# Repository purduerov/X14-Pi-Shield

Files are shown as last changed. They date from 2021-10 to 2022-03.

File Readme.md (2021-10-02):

# Readme for X14-Pi-Shield

Whenever you make a new part, download the datasheet and save it here _**and**_ with the part in the parts library

Always pull other people's changes before beginning to work
`git pull`

Be sure to push your changes after  working on them. Run:
1. `git add .` to add any files in this directory or a subdirectory
or `git add -u` to add any modified files
2. (Optional) `git clean -nX` to see what ignored files can be removed
	`git clean -fX` removes ignored files (Eagle backups)
3. `git commit -m "helpful commit message"` with a description of the work that you did
4. `git push` to push your work to github

Other helpful commands
* `git status` says information about modified and staged files
* `git log` shows the recent commits of the repository
* `git log filename.extension` show the recent commits for just that file
* `git checkout first-couple-letter-of-commit-id` lets you go back to a previous version
* `git checkout master` brings you back to the latest commit
* `git tag` lists the tags
* `git tag -a orderX -m "the version of the board placed for the X'th order"` tag a specific commit
* `git push --tags` needed to push tags to remote
* `git show orderX` show the commit log for the given tag
* `git checkout orderX` go back and interact with the files at the tagged commit

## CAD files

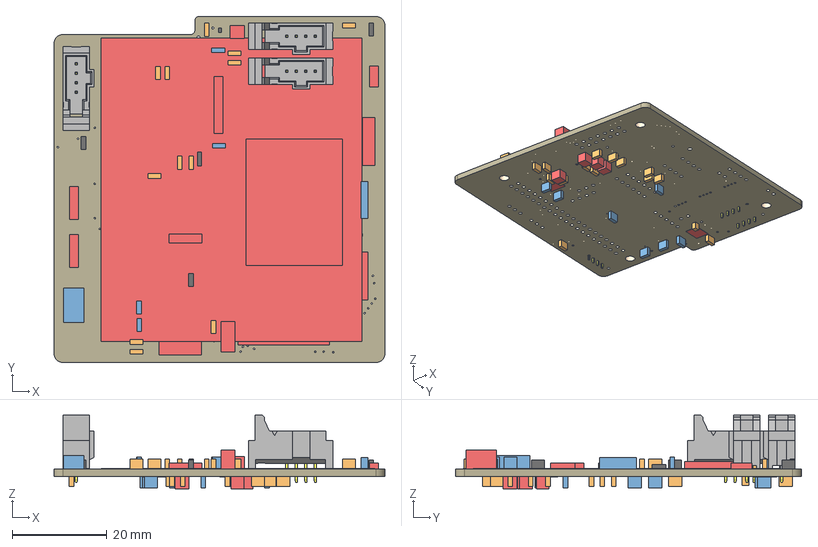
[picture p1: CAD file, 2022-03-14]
PI-Shield.step
69.8 x 73.0 x 15.5 mm
Board
0.1uF x 11
47uF
150uF
250mA/100V
COLOR
LED-0603 x 3
1X04 x 2
_T2I-04-VT-T-S-TH_terminal x 3
_T2I-04-VT-T-S-TH_pins x 3
DF13-4P-1.25DSA x 3
1X03 x 3
1X05
1X02
1X02 (1) x 2
2.5A/30V/105mΩ x 5
JUMPER-SMT_2_NO_SILK
MCP2515
TCAN337D
ADAFRUIT-FXOS8700-FXAS21002
ADAFRUIT-BNO055
DISCRETECOMPONENTS_SW_2512
MCR1101
RPI4
MAX1136EUA-T
ULN2003V12
ECS-80-S-4X
7X_CONN

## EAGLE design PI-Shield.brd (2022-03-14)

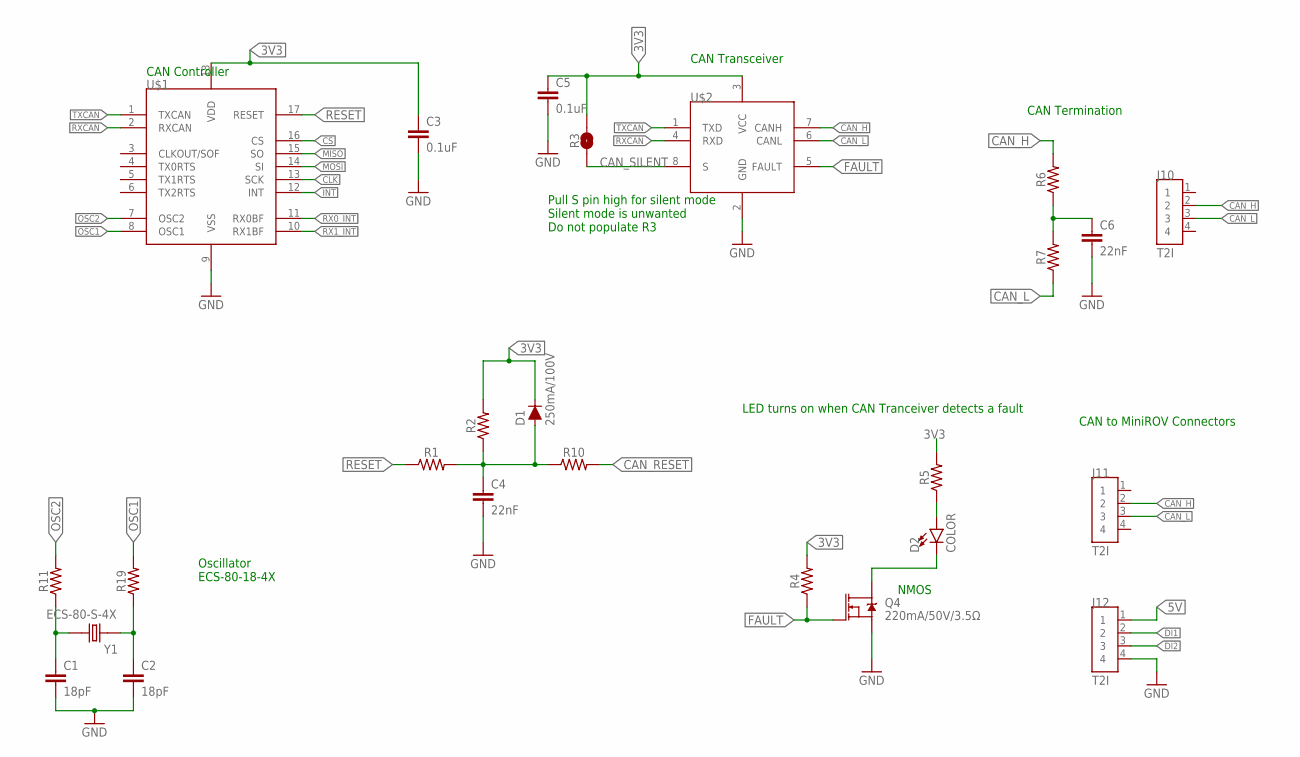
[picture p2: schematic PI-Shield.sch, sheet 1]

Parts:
C1, C2: 18pF; 0603
C3, C5: 0.1uF; 0603
C4, C6: 22nF; 0603
D1: 250mA/100V; SOD-323
D2: COLOR; 0805
J10, J11, J12: T2I
Q4: 220mA/50V/3.5Ω; SOT23-3
R1, R2, R4, R5, R6, R7, R10, R11, R19: 0603
R3: JUMPER-SMT_2_NO_SILK; SMT-JUMPER_2_NO_SILK
U$1: MCP2515; SOIC-18
U$2: TCAN337D; SOIC-8
Y1: ECS-80-S-4X; XTAL_ECS-80-S-4X

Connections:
3V3: C3.1, C5.1, D1.C, R2.2, R3.2, R4.2, R5.2, U$1.18 (VDD), U$2.3 (VCC); also elsewhere on the board
5V: J12.1; also elsewhere on the board
CAN_H: J10.2, J11.2, R6.2, U$2.7 (CANH); also elsewhere on the board
CAN_L: J10.3, J11.3, R7.1, U$2.6 (CANL); also elsewhere on the board
CAN_RESET: R10.2; also elsewhere on the board
CAN_SILENT: R3.1, U$2.8 (S)
CAN_TERM_COM: C6.1, R6.1, R7.2
CLK: U$1.13 (SCK); also elsewhere on the board
CS: U$1.16 (CS); also elsewhere on the board
DI1: J12.2; also elsewhere on the board
DI2: J12.3; also elsewhere on the board
FAULT: Q4.1 (G), R4.1, U$2.5 (FAULT)
GND: C1.2, C2.2, C3.2, C4.2, C5.2, C6.2, J12.4, Q4.2 (S), U$1.9 (VSS), U$2.2 (GND); also elsewhere on the board
INT: U$1.12 (INT); also elsewhere on the board
MISO: U$1.15 (SO); also elsewhere on the board
MOSI: U$1.14 (SI); also elsewhere on the board
unnamed: C1.1, R11.1, Y1.2
unnamed: C2.1, R19.1, Y1.1
unnamed: D2.C, Q4.3 (D)
unnamed: D2.A, R5.1
OSC1: R19.2, U$1.8 (OSC1)
OSC2: R11.2, U$1.7 (OSC2)
RESET: R1.1, U$1.17 (RESET)
RESET_MID: C4.1, D1.A, R1.2, R2.1, R10.1
RX0_INT: U$1.11 (RX0BF); also elsewhere on the board
RX1_INT: U$1.10 (RX1BF); also elsewhere on the board
RXCAN: U$1.2 (RXCAN), U$2.4 (RXD)
TXCAN: U$1.1 (TXCAN), U$2.1 (TXD)

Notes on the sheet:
Oscillator ECS-80-18-4X
CAN Termination
CAN to MiniROV Connectors
NMOS
CAN Controller
CAN Transceiver
Pull S pin high for silent mode Silent mode is unwanted Do not populate R3
LED turns on when CAN Tranceiver detects a fault

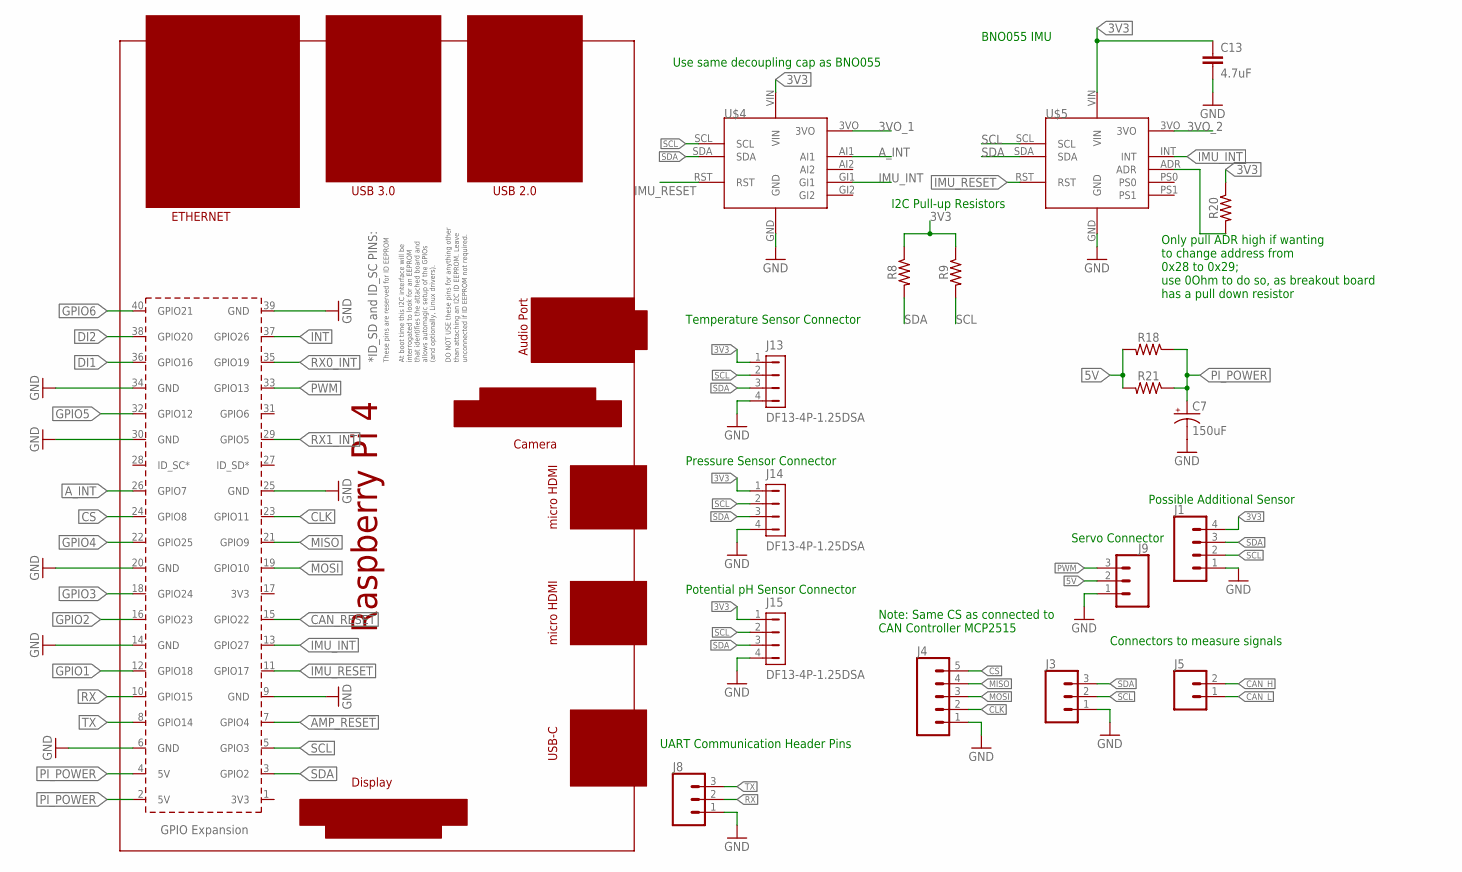
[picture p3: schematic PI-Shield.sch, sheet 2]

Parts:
C7: 150uF; 2917(7343-31-METRIC)
C13: 4.7uF; 0603
J1: CONN_04; 1X04
J3, J8, J9: CONN_03; 1X03
J4: CONN_05; 1X05
J5: CONN_02; 1X02
J13, J14, J15: DF13-4P-1.25DSA
R8, R9, R18, R20, R21: 0603
U$4: ADAFRUIT-FXOS8700-FXAS21002
U$5: ADAFRUIT-BNO055
U$8: RPI4

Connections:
3V3: C13.1, J1.4, J13.1, J14.1, J15.1, R8.1, R9.1, R20.1, U$4.VIN, U$5.VIN; also elsewhere on the board
3VO_1: U$4.3VO
3VO_2: U$5.3VO
5V: J9.2, R18.2, R21.2; also elsewhere on the board
!AMP_RESET: U$8.7 (GPIO4); also elsewhere on the board
A_INT: U$4.AI1, U$8.26 (GPIO7)
CAN_H: J5.2; also elsewhere on the board
CAN_L: J5.1; also elsewhere on the board
CAN_RESET: U$8.15 (GPIO22); also elsewhere on the board
CLK: J4.2, U$8.23 (GPIO11); also elsewhere on the board
CS: J4.5, U$8.24 (GPIO8); also elsewhere on the board
DI1: U$8.36 (GPIO16); also elsewhere on the board
DI2: U$8.38 (GPIO20); also elsewhere on the board
GND: C7.-, C13.2, J1.1, J3.1, J4.1, J8.1, J9.1, J13.4, J14.4, J15.4, U$4.GND, U$5.GND, U$8.6 (GND), U$8.9 (GND), U$8.14 (GND), U$8.20 (GND), U$8.25 (GND), U$8.30 (GND), U$8.34 (GND), U$8.39 (GND); also elsewhere on the board
GPIO1: U$8.12 (GPIO18); also elsewhere on the board
GPIO2: U$8.16 (GPIO23); also elsewhere on the board
GPIO3: U$8.18 (GPIO24); also elsewhere on the board
GPIO4: U$8.22 (GPIO25); also elsewhere on the board
GPIO5: U$8.32 (GPIO12); also elsewhere on the board
GPIO6: U$8.40 (GPIO21); also elsewhere on the board
IMU_INT: U$4.GI1, U$5.INT, U$8.13 (GPIO27)
IMU_RESET: U$4.RST, U$5.RST, U$8.11 (GPIO17)
INT: U$8.37 (GPIO26); also elsewhere on the board
MISO: J4.4, U$8.21 (GPIO9); also elsewhere on the board
MOSI: J4.3, U$8.19 (GPIO10); also elsewhere on the board
unnamed: R20.2, U$5.ADR
PI_POWER: C7.+, R18.1, R21.1, U$8.2 (5V), U$8.4 (5V)
PWM: J9.3, U$8.33 (GPIO13)
RX: J8.2, U$8.10 (GPIO15)
RX0_INT: U$8.35 (GPIO19); also elsewhere on the board
RX1_INT: U$8.29 (GPIO5); also elsewhere on the board
SCL: J1.2, J3.2, J13.2, J14.2, J15.2, R9.2, U$4.SCL, U$5.SCL, U$8.5 (GPIO3); also elsewhere on the board
SDA: J1.3, J3.3, J13.3, J14.3, J15.3, R8.2, U$4.SDA, U$5.SDA, U$8.3 (GPIO2); also elsewhere on the board
TX: J8.3, U$8.8 (GPIO14)

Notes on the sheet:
Connectors to measure signals
Temperature Sensor Connector
Pressure Sensor Connector
Potential pH Sensor Connector
BNO055 IMU
Possible Additional Sensor
UART Communication Header Pins
Servo Connector
Only pull ADR high if wanting to change address from 0x28 to 0x29; use 0Ohm to do so, as breakout board has a pull down resistor
Use same decoupling cap as BNO055
I2C Pull-up Resistors
Note: Same CS as connected to CAN Controller MCP2515

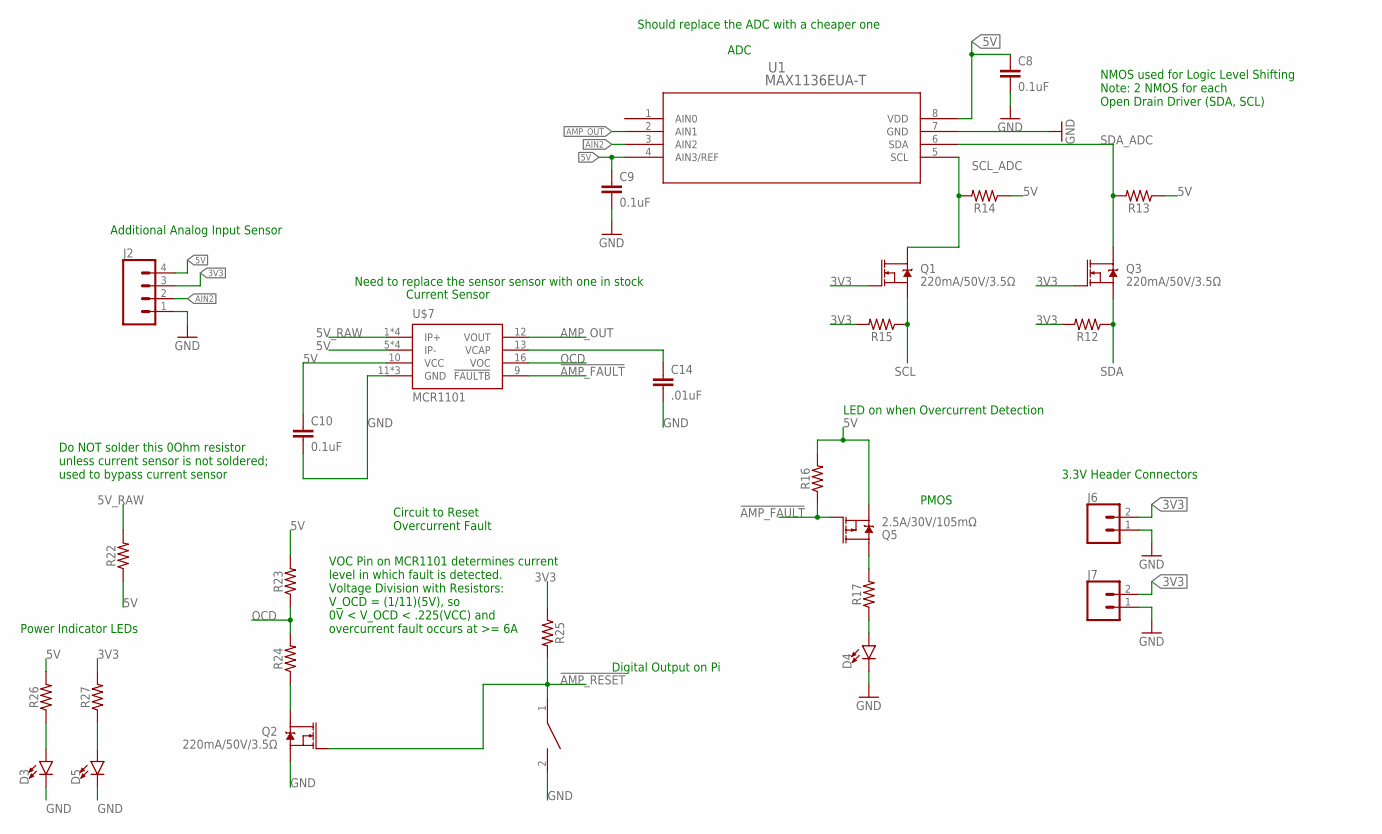
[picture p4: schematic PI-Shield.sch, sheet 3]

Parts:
C8, C9, C10: 0.1uF; 0603
C14: .01uF; 0603
D3, D4, D5: LED0603; LED-0603
J2: CONN_04; 1X04
J6, J7: CONN_02; 1X02
Q1, Q2, Q3: 220mA/50V/3.5Ω; SOT23-3
Q5: 2.5A/30V/105mΩ; SOT23-3
R12, R13, R14, R15, R16, R17, R22, R23, R24, R25, R26, R27: 0603
U1: MAX1136EUA-T; 21-0036K
U$6: DISCRETECOMPONENTS_SWITCH; DISCRETECOMPONENTS_SW_2512
U$7: MCR1101; SOIC-16

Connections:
3V3: J2.3, J6.2, J7.2, Q1.1 (G), Q3.1 (G), R12.2, R15.2, R25.1, R27.2; also elsewhere on the board
5V: C8.1, C9.1, C10.1, J2.4, Q5.2 (S), R13.1, R14.1, R16.2, R22.1, R23.2, R26.2, U1.4 (AIN3/REF), U1.8 (VDD), U$7.5 (IP-), U$7.6 (IP-), U$7.7 (IP-), U$7.8 (IP-), U$7.10 (VCC); also elsewhere on the board
5V_RAW: R22.2, U$7.1 (IP+), U$7.2 (IP+), U$7.3 (IP+), U$7.4 (IP+)
!AMP_FAULT: Q5.1 (G), R16.1, U$7.9 (!FAULTB)
!AMP_RESET: Q2.1 (G), R25.2, U$6.1; also elsewhere on the board
AIN2: J2.2, U1.3 (AIN2)
AMP_OUT: U1.2 (AIN1), U$7.12 (VOUT)
GND: C8.2, C9.2, C10.2, C14.2, D3.C, D4.C, D5.C, J2.1, J6.1, J7.1, Q2.2 (S), U1.7 (GND), U$6.2, U$7.11 (GND), U$7.14 (GND), U$7.15 (GND); also elsewhere on the board
unnamed: C14.1, U$7.13 (VCAP)
unnamed: D3.A, R26.1
unnamed: Q5.3 (D), R17.2
unnamed: D4.A, R17.1
unnamed: D5.A, R27.1
unnamed: Q2.3 (D), R24.1
OCD: R23.1, R24.2, U$7.16 (VOC)
SCL: Q1.2 (S), R15.1; also elsewhere on the board
SCL_ADC: Q1.3 (D), R14.2, U1.5 (SCL)
SDA: Q3.2 (S), R12.1; also elsewhere on the board
SDA_ADC: Q3.3 (D), R13.2, U1.6 (SDA)

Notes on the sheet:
ADC
Additional Analog Input Sensor
3.3V Header Connectors
PMOS
LED on when Overcurrent Detection
NMOS used for Logic Level Shifting Note: 2 NMOS for each Open Drain Driver (SDA, SCL)
Do NOT solder this 0Ohm resistor unless current sensor is not soldered; used to bypass current sensor
Current Sensor
Circuit to Reset Overcurrent Fault
Need to replace the sensor sensor with one in stock
Should replace the ADC with a cheaper one
Power Indicator LEDs
VOC Pin on MCR1101 determines current level in which fault is detected. Voltage Division with Resistors: V_OCD = (1/11)(5V), so 0V < V_OCD < .225(VCC) and overcurrent fault occurs at >= 6A
Digital Output on Pi

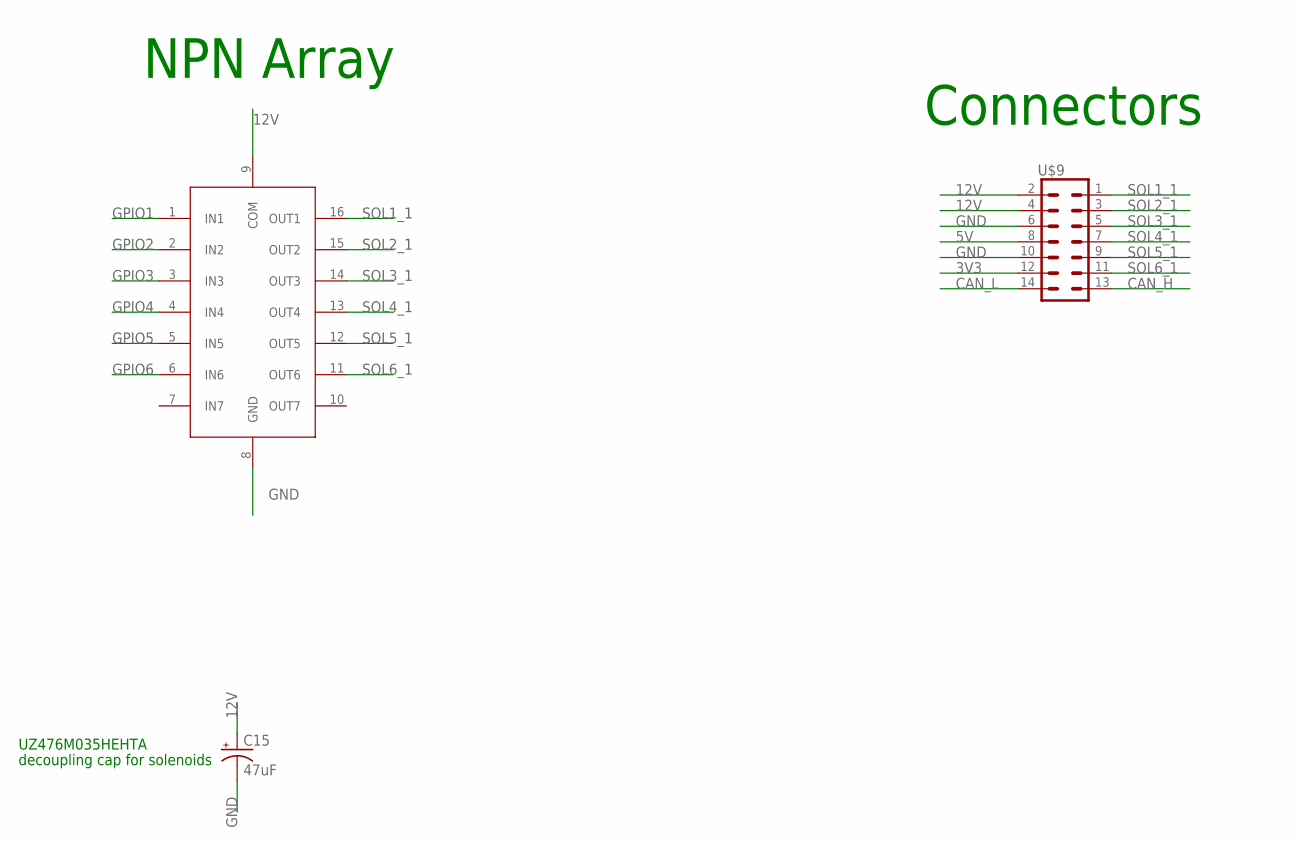
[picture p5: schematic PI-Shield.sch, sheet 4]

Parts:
C15: 47uF; PANASONIC_D
U3: ULN2003V12
U$9: 7X_CONN; IPL7X2

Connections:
3V3: U$9.12 (23); also elsewhere on the board
5V: U$9.8 (19); also elsewhere on the board
12V: C15.+, U3.9 (COM), U$9.2 (13), U$9.4 (15)
CAN_H: U$9.13 (1); also elsewhere on the board
CAN_L: U$9.14 (2); also elsewhere on the board
GND: C15.-, U3.8 (GND), U$9.6 (17), U$9.10 (21); also elsewhere on the board
GPIO1: U3.1 (IN1); also elsewhere on the board
GPIO2: U3.2 (IN2); also elsewhere on the board
GPIO3: U3.3 (IN3); also elsewhere on the board
GPIO4: U3.4 (IN4); also elsewhere on the board
GPIO5: U3.5 (IN5); also elsewhere on the board
GPIO6: U3.6 (IN6); also elsewhere on the board
SOL1_1: U3.16 (OUT1), U$9.1 (14)
SOL2_1: U3.15 (OUT2), U$9.3 (16)
SOL3_1: U3.14 (OUT3), U$9.5 (18)
SOL4_1: U3.13 (OUT4), U$9.7 (20)
SOL5_1: U3.12 (OUT5), U$9.9 (22)
SOL6_1: U3.11 (OUT6), U$9.11 (24)

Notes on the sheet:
NPN Array
Connectors
decoupling cap for solenoids
UZ476M035HEHTA

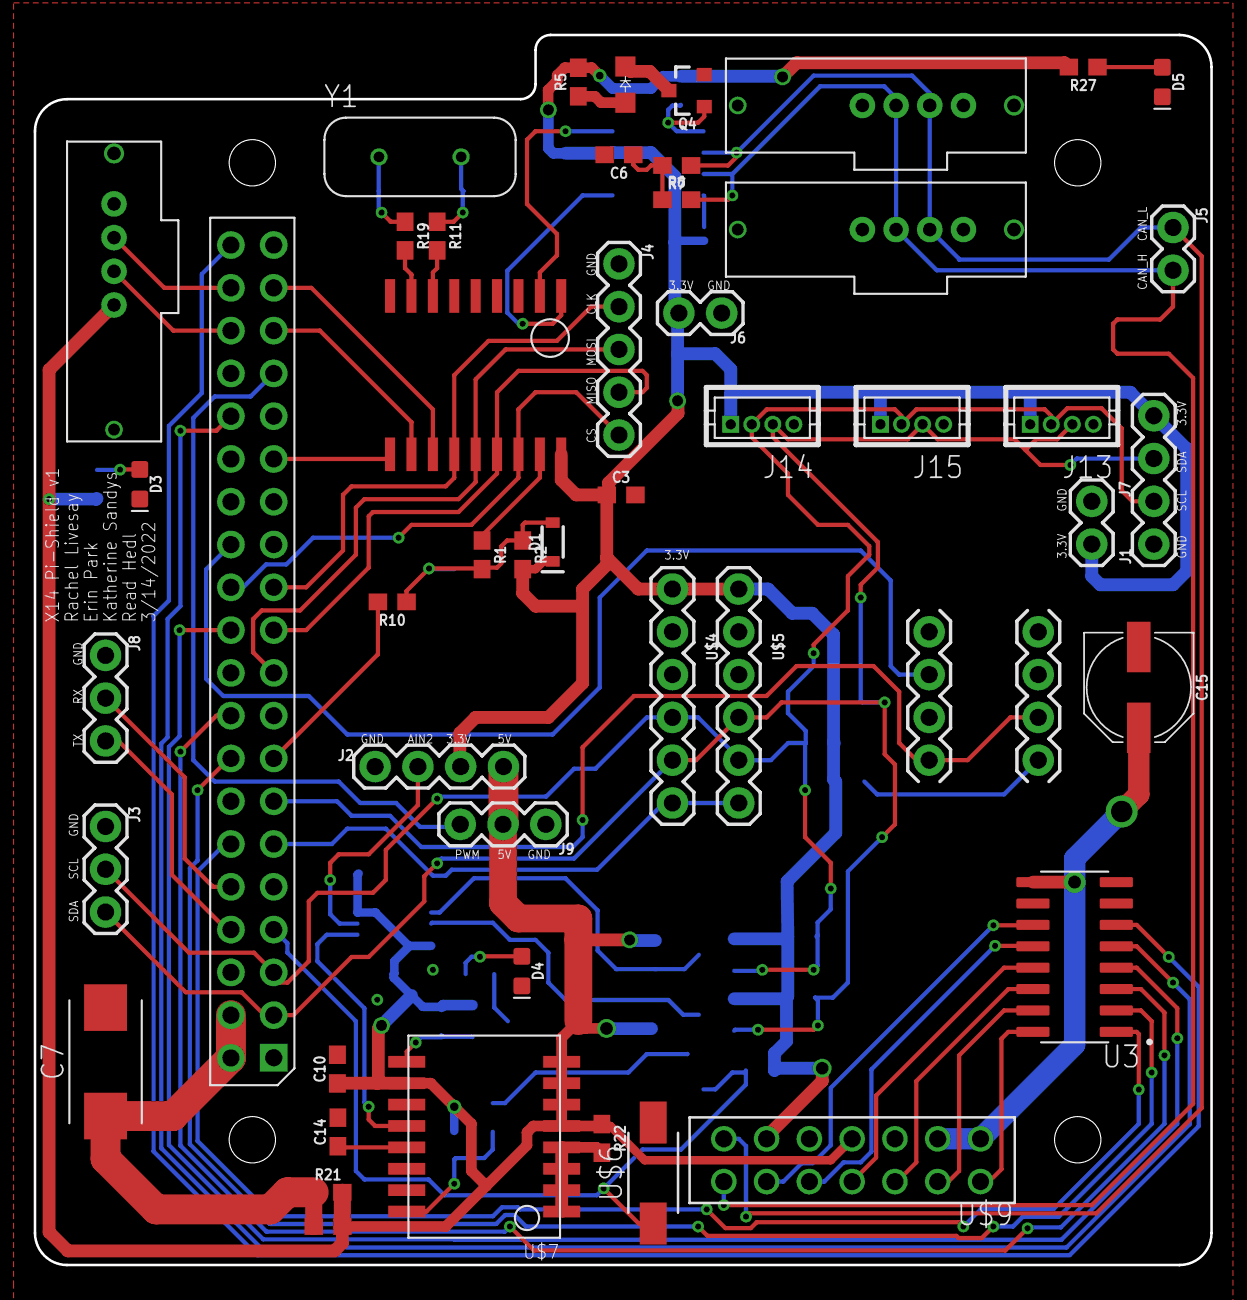
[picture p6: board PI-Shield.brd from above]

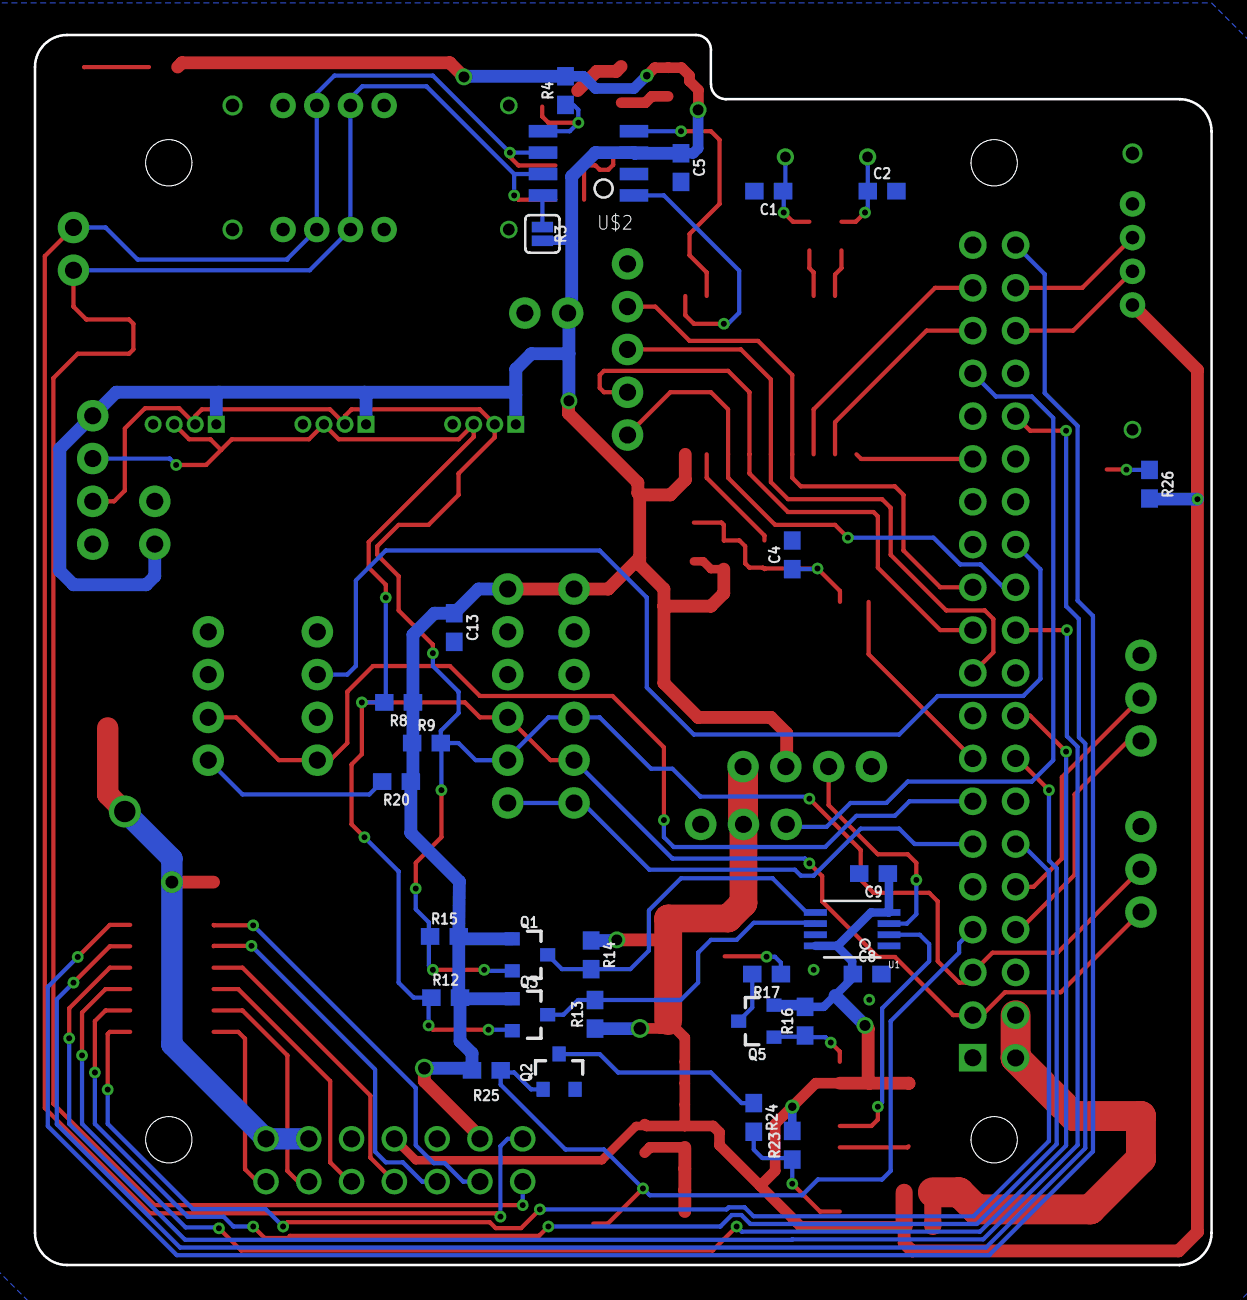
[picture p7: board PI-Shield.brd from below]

Board: 2 copper layers, 69.8 x 73.0 mm, 76 parts (28 on the bottom side), 65 nets.

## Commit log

2021-10-06 initial commit
    (finally, needed to reinstall GitHub :P)
    [Changes: merged solenoid and shield schematics, removed STM]
    [To Do: Add connectors for 12V to solenoid, make it look pretty]
    [PI-Shield.sch]
2021-10-23 Schematic Update
    Changes: [Added GPIO extender, wired up to SDA/SCL; removed owos]
    [PI-Shield.sch]
2021-11-06 Sch Update, Added Board
    [Changes: Removed micro-USB, Added 47uF cap between 12v and GND, added new connector to backplane (added lib to X-14-parts-library), A0-A2 on GPIO Expander grounded.]
    [To Do: Add TVS diode between SCL/SDA, Connect open drain output on GPIO expander.]
    [PI-Shield.brd, PI-Shield.sch]
2021-11-30 Board Update
    Changes: [Reduced backplane connector from 26->12 positions, added board outline matching last year's, placement of components]
    To Do: [Routing, which should be done within next 24 hrs :P]
    [PI-Shield.brd, PI-Shield.sch]
2021-11-30 Schematic Update
    Changes: [FREAKING FORGOT TO LABEL A PIN >:((((]
    [PI-Shield.brd, PI-Shield.sch]
2021-12-02 Routing Hard >:(
    Changes: [Started routing,,,,, it's going well???? i dunno, *power polygons*]
    [PI-Shield.brd]
2021-12-04 Routing :)
    Change: [bro why this game of flow so hard??]
    [PI-Shield.brd]
2021-12-04 Fixed Like 2 Routes smh
    [PI-Shield.brd]
2021-12-19 Alumni Design Updates
    Changes: [Trace Matched SCL/SDA & TX/RX, added alumni feedback]
    [PI-Shield.brd, PI-Shield.sch]
2022-03-11 v2 Changes
    Would like to formally apologize for the routing of the GPIO on the bottom of the board. It was necessary, unfortunately.
    Changes: [Removed expander, added LED and Header Labels, really shitty routing.]
    [PI-Shield.brd, PI-Shield.sch]
2022-03-14 Adjusted some labels, fixed minor errors
    [PI-Shield.brd, PI-Shield.sch]
2022-03-14 Replaced R3 with Jumper, exported STEP
    [PI-Shield.brd, PI-Shield.sch, PI-Shield.step]

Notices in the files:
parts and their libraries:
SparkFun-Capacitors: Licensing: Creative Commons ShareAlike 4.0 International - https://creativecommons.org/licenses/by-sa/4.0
